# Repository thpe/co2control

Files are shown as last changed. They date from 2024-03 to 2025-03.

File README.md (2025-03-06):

# CO2 control
Monitor for CO2
## Features
 * EIA-485 interface
 * SCD-30 sensor
 * Input volatage 24 V
 * RP-2040
 * 4 LEDs
 * Relay
 * Oxygen Cell input < 150 mV (not yet tested)
 * 0-10 V output
 * 1 wire interface
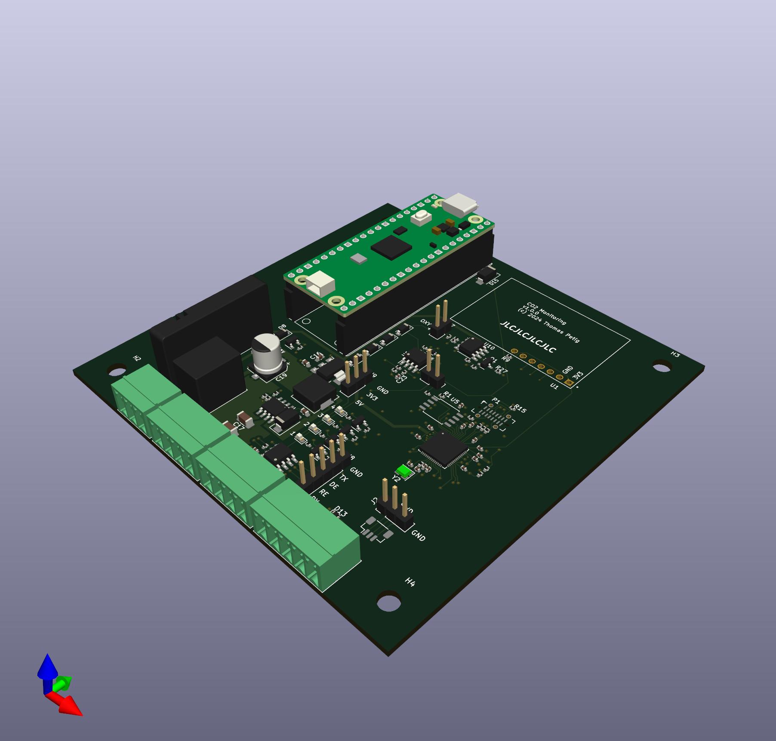
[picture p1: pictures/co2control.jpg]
board3d


## Issues and Limitations
The following issues with the current versions are known:
 * RX/TX to SCD30 need to be switched
 * doesn't connect via USB
   * USB C symbol should have been a receptable, not plug
   * Thus, B7/B6 are not connected to D+/-

## Connection
XLR male, pinout
 * 1. GND, Blue
 * 2. +24V, Blue/White
 * 3. 485A, Orange
 * 4. 485B, Orange/White

## Firmware
The [co2control-fw](https://github.com/thpe/co2control-fw) firmware samples the SCD-30 regulary and exposes the measurements via
modbus.

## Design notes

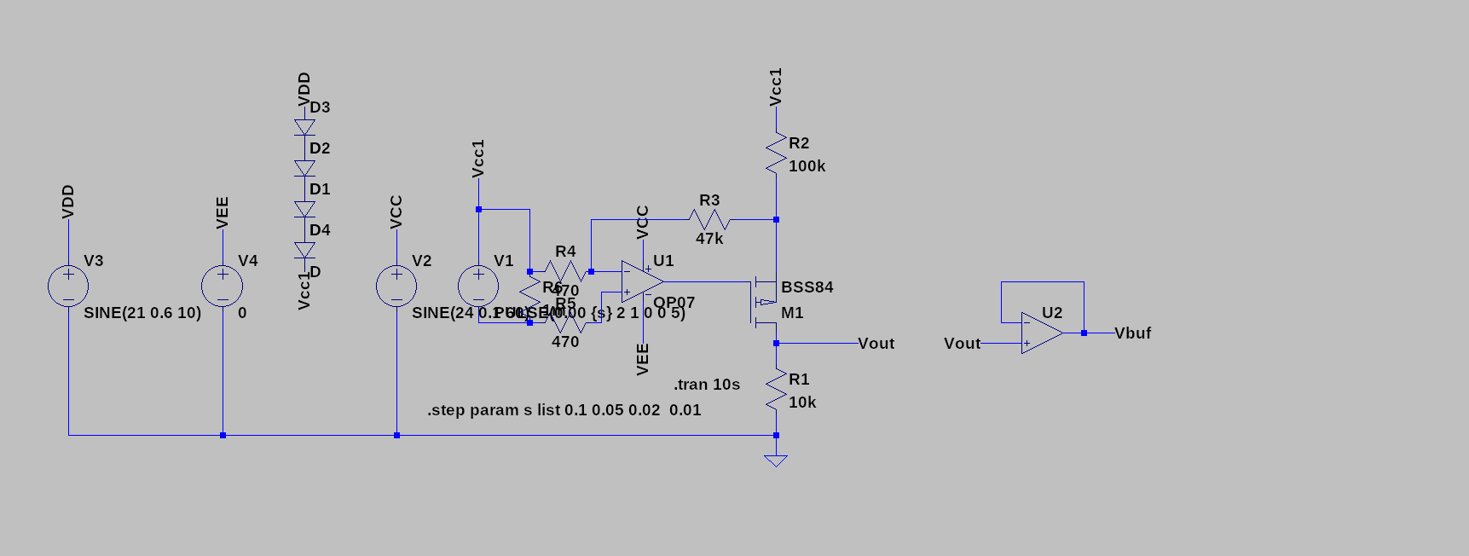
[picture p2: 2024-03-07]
sim/schema.png

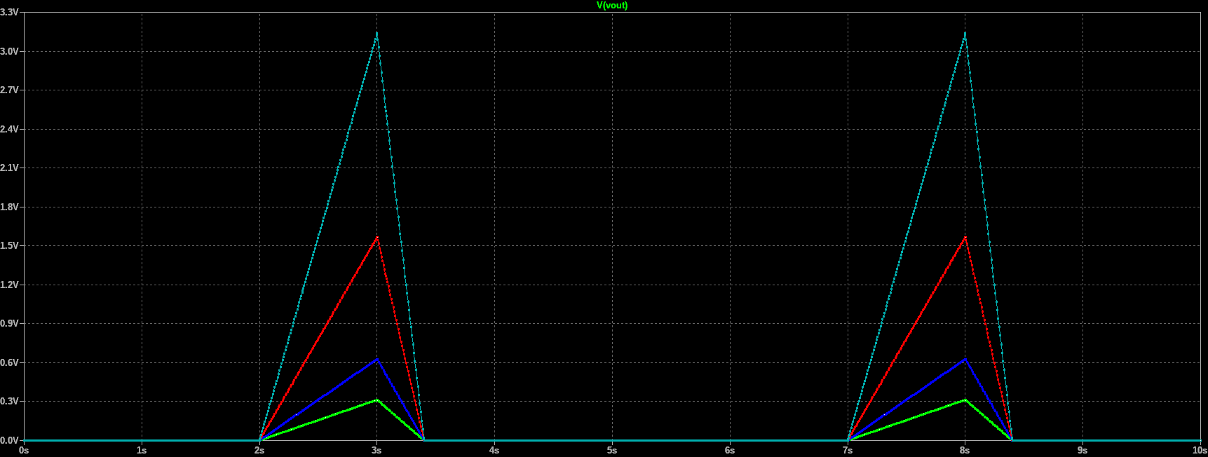
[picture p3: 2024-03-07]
sim/plot.png

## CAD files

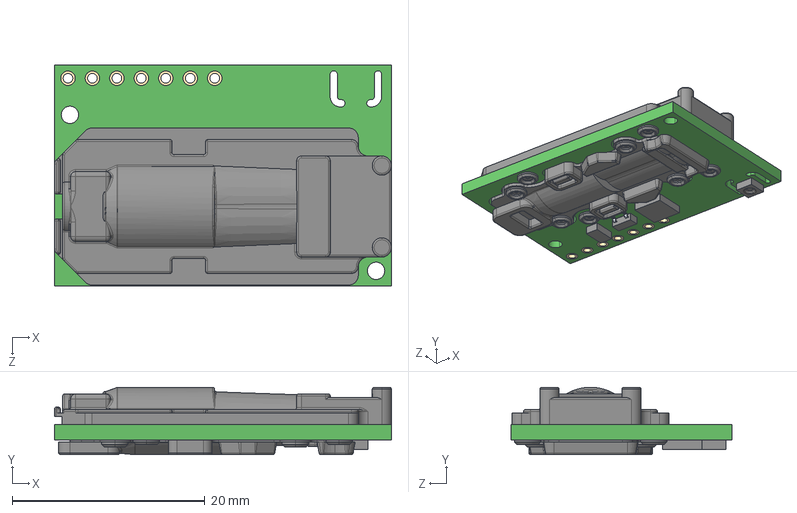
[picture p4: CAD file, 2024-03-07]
scd30/SCD30.step
35.0 x 7.00 x 23.0 mm

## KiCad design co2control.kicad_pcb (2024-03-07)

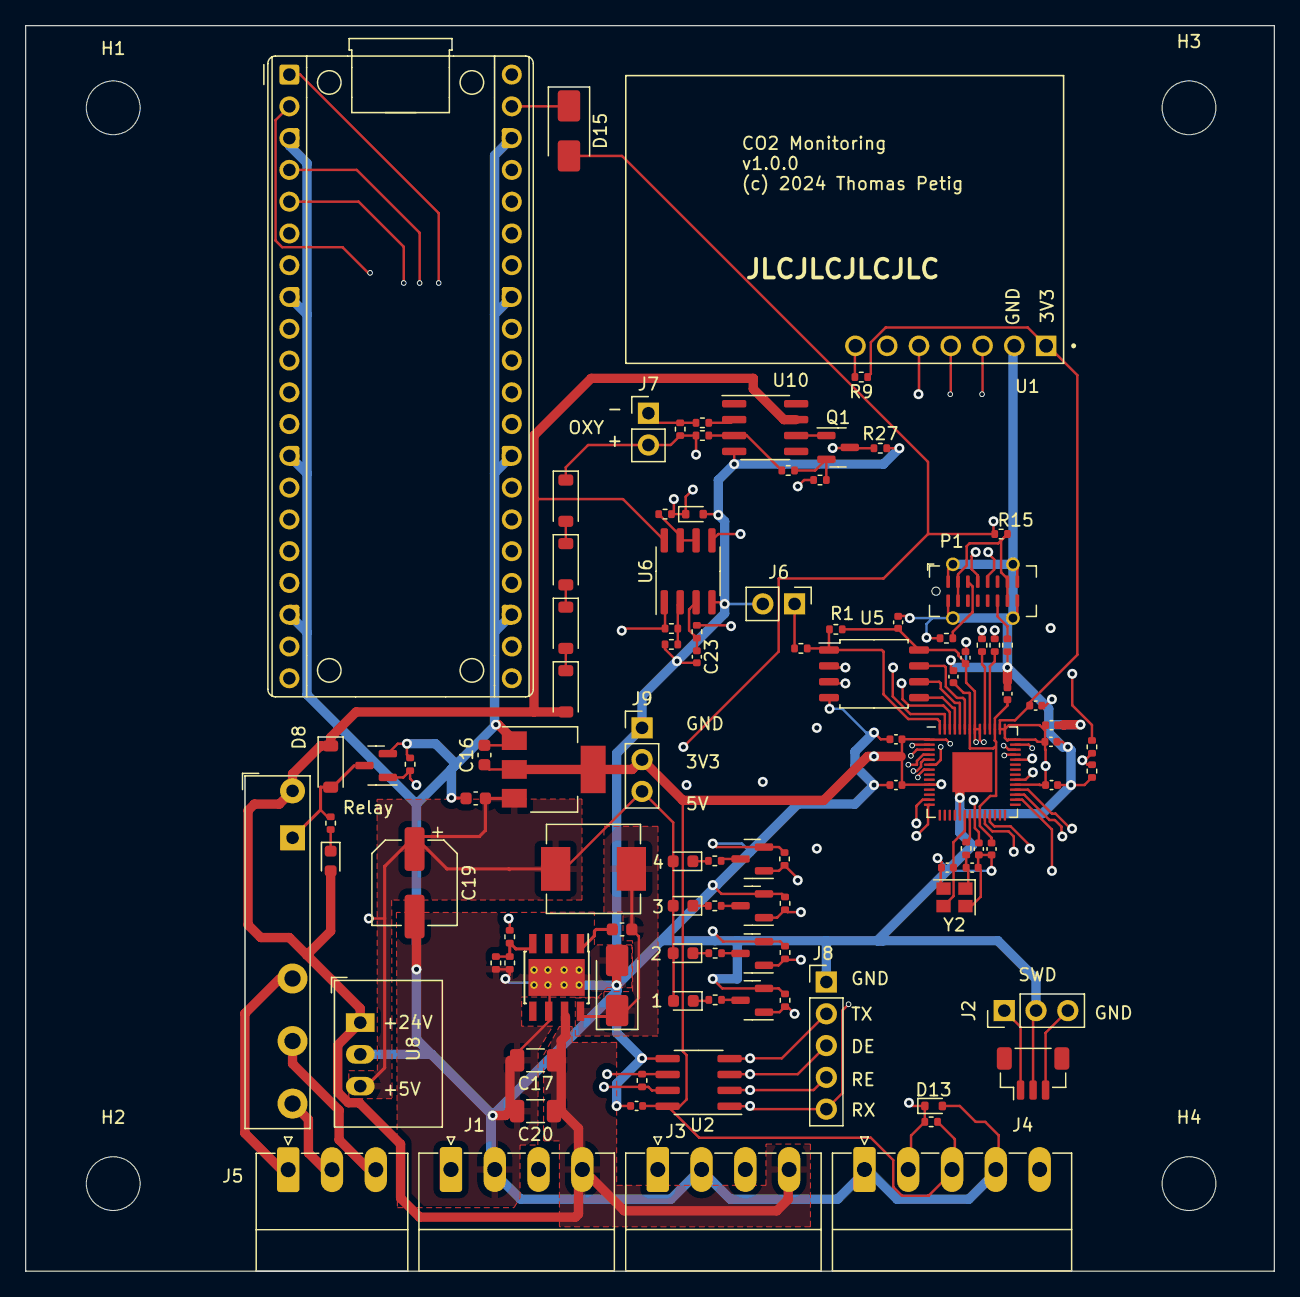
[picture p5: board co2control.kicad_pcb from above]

Board: 4 copper layers, 99.8 x 99.6 mm, 106 parts (0 on the bottom side), 74 nets.

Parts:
C1, C4, C5, C6, C7, C8, C9, C10, C11, C12: 100n; C_0402_1005Metric
C2, C3, C23: 10p; C_0402_1005Metric
C13, C14: 1u; C_0402_1005Metric
C15, C16: 10u; C_0603_1608Metric
C17, C20: 4u7, 50V; C_1206_3216Metric
C18: 10n; C_0603_1608Metric
C19: 220u; CP_Elec_6.3x7.7
C21: 10n; C_0402_1005Metric
D2, D15: B340; D_SMA
D3, D4, D5, D6, D14: LED; LED_0603_1608Metric
D7, D8, D9, D10, D11: 1N4148W; D_SOD-123
D12, D13: MM5Z3V9; D_SOD-523
H1: MountingHole; MountingHole_4.3mm_M4_DIN965
H2, H3, H4: MountingHole; MountingHole_4.3mm_M4
J1, J3: Conn_01x04; PhoenixContact_MC_1,5_4-G-3.5_1x04_P3.50mm_Horizontal
J2: Conn_01x03_Pin; PinHeader_1x03_P2.54mm_Vertical
J4: Conn_01x05; PhoenixContact_MC_1,5_5-G-3.5_1x05_P3.50mm_Horizontal
J5: Conn_01x03; PhoenixContact_MC_1,5_3-G-3.5_1x03_P3.50mm_Horizontal
J6, J7: Conn_01x02; PinHeader_1x02_P2.54mm_Vertical
J8: Conn_01x05; PinHeader_1x05_P2.54mm_Vertical
J9: Conn_01x03; PinHeader_1x03_P2.54mm_Vertical
J10: Conn_01x03_Pin; JST_SH_BM03B-SRSS-TB_1x03-1MP_P1.00mm_Vertical
K1: Relay_SPDT; Relay_SPDT_Finder_34.51_Vertical
L1: 22u; L_Sunlord_MWSA0603S
P1: USB_C_Plug_USB2.0; USB_C_Receptacle_G-Switch_GT-USB-7051x
Q1: Q_PMOS_GSD; SOT-23
Q2, Q3, Q4, Q5, Q6: BSS138; SOT-23
R1, R15: DNF; R_0402_1005Metric
R2, R3, R16: 1k; R_0402_1005Metric
R4, R5: 27; R_0402_1005Metric
R6: 120; R_0402_1005Metric
R7, R9, R17, R19, R20, R27, R32, R33: 10k; R_0402_1005Metric
R8: 3k3; R_0402_1005Metric
R10, R12, R13, R30: 220; R_0402_1005Metric
R11, R22, R25, R26, R28, R29, R31, R36: 100k; R_0402_1005Metric
R14: 1M; R_0402_1005Metric
R18: 1k5; R_0402_1005Metric
R21: 4k7; R_0402_1005Metric
R23, R24: 330; R_0402_1005Metric
R34, R35: 5k1; R_0402_1005Metric
U1: SCD30; MODULE_SCD30
U2: SP3485EN; SOIC-8_3.9x4.9mm_P1.27mm
U3: AP1117-33; SOT-223-3_TabPin2
U4: RP2040; QFN-56-1EP_7x7mm_P0.4mm_EP3.2x3.2mm
U5: W25Q128JVS; SOIC-8_5.23x5.23mm_P1.27mm
U6: LM358; SOIC-8_3.9x4.9mm_P1.27mm
U7: RaspberryPi_Pico; RaspberryPi_Pico_Common_THT
U8: R-78C5.0-1.0; Converter_DCDC_RECOM_R-78E-0.5_THT
U9: TPS5430DDA; TI_SO-PowerPAD-8_ThermalVias
U10: OP07; SOIC-8_3.9x4.9mm_P1.27mm
Y2: 7E12000E10UCG; Crystal_SMD_2520-4Pin_2.5x2.0mm

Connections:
+1V1: C11.1, C12.1, C14.1, U4.23 (DVDD), U4.45 (VREG_VOUT), U4.50 (DVDD)
+3.3V: C1.1, C4.1, C5.1, C6.1, C7.1, C8.1, C9.1, C10.1, C13.1, C16.1, C21.1, J4.3, J9.2, R1.1, R9.1, R17.2, U1.1 (VDD), U2.8 (VCC), U3.2 (VO), U4.1 (IOVDD), U4.10 (IOVDD), U4.22 (IOVDD), U4.33 (IOVDD), U4.42 (IOVDD), U4.43 (ADC_AVDD), U4.44 (VREG_IN), U4.48 (USB_VDD), U4.49 (IOVDD), U5.8 (VCC)
+5V: C15.1, C19.1, D3.2 (A), D4.2 (A), D5.2 (A), D6.2 (A), D15.2 (A), J9.3, L1.2, R7.1, R15.2, R32.1, U3.3 (VI), U8.3 (OUT)
+24V: C17.1, C20.1, D7.2 (A), D8.1 (K), D14.2 (A), J1.4, J3.4, K1.A2, U6.8 (V+), U8.1 (IN), U9.7 (VIN), U10.7 (V+)
/io/1wire: D13.1 (K), J4.2, R17.1, U4.14 (GPIO11), U7.15 (GPIO11)
/io/485A: J1.1, J3.1, R6.1, U2.6 (A)
/io/485B: J1.3, J3.3, R6.2, U2.7 (B)
/io/MODBUS_DE: J8.3, U2.3 (DE), U4.4 (GPIO2), U7.4 (GPIO2)
/io/MODBUS_RE: J8.4, U2.2 (~RE), U4.5 (GPIO3), U7.5 (GPIO3)
/io/MODBUS_RX: J8.5, U2.1 (RO), U4.3 (GPIO1), U7.2 (GPIO1)
/io/MODBUS_TX: J8.2, U2.4 (DI), U4.2 (GPIO0), U7.1 (GPIO0)
/io/OUT1_10V: J4.5, R19.1, U6.1
/io/PWM1: R21.2, U4.13 (GPIO10), U7.14 (GPIO10)
/io/RELAY: Q2.1 (G), R22.2, U4.39 (GPIO27_ADC1), U7.32 (GPIO27_ADC1)
/io/Voxy: D12.1 (K), R16.1, U4.38 (GPIO26_ADC0), U7.31 (GPIO26_ADC0)
/power/PH: C18.2, D2.1 (K), L1.1, U9.8 (PH)
/processing/ADC2: U1.5 (RDY), U4.40 (GPIO28_ADC2), U7.34 (GPIO28_ADC2)
/processing/LED1: Q6.1 (G), R31.2, U4.30 (GPIO19), U7.25 (GPIO19)
/processing/LED2: Q4.1 (G), R11.2, U4.31 (GPIO20), U7.26 (GPIO20)
/processing/LED3: Q5.1 (G), R29.2, U4.32 (GPIO21), U7.27 (GPIO21)
/processing/LED4: Q3.1 (G), R28.2, U4.34 (GPIO22), U7.29 (GPIO22)
/processing/UART1 RX: U1.4 (RX/SDA), U4.7 (GPIO5), U7.7 (GPIO5)
/processing/UART1 TX: U1.3 (TX/SCL), U4.6 (GPIO4), U7.6 (GPIO4)
/processing/USB_D+: P1.A6 (D+), R5.1
/processing/USB_D-: P1.A7 (D-), R4.2
GND: C1.2, C2.1, C3.1, C4.2, C5.2, C6.2, C7.2, C8.2, C9.2, C10.2, C11.2, C12.2, C13.2, C14.2, C15.2, C16.2, C17.2, C19.2, C20.2, C21.2, C23.2, D2.2 (A), D12.2 (A), D13.2 (A), J1.2, J2.2, J3.2, J4.1, J4.4, J6.2, J8.1, J9.1, J10.2, P1.A1 (GND), P1.A12 (GND), P1.B1 (GND), P1.B12 (GND), P1.S1 (SHIELD), Q2.2 (S), Q3.2 (S), Q4.2 (S), Q5.2 (S), Q6.2 (S), R8.2, R11.1, R20.1, R22.1, R27.2, R28.1, R29.1, R31.1, R33.2, R34.1, R35.1, R36.2, U1.2 (GND), U2.5 (GND), U3.1 (GND), U4.19 (TESTEN), U4.57 (GND), U5.4 (GND), U6.4 (V-), U7.3 (GND), U7.8 (GND), U7.13 (GND), U7.18 (GND), U7.23 (GND), U7.28 (GND), U7.33 (AGND), U7.38 (GND), U8.2 (GND), U9.6 (GND), U9.9 (GNDPAD), U10.4 (V-), Y2.2, Y2.4
unnamed: C3.2, R3.1, Y2.1
unnamed: D3.1 (K), R10.1
unnamed: D4.1 (K), R12.1
unnamed: D5.1 (K), R30.1
unnamed: D6.1 (K), R13.1
unnamed: D7.1 (K), D9.2 (A)
unnamed: D8.2 (A), K1.A1, Q2.3 (D), R18.2
unnamed: D9.1 (K), D10.2 (A)
unnamed: D10.1 (K), D11.2 (A)
unnamed: D11.1 (K), J7.2, R14.1, R23.1, R26.1
unnamed: D14.1 (K), R18.1
unnamed: D15.1 (K), U7.39 (VSYS)
unnamed: J5.1, K1.12
unnamed: J5.2, K1.14
unnamed: J5.3, K1.11
unnamed: J6.1, R2.1
unnamed: J7.1, R14.2, R24.1
unnamed: J2.1, J10.1, U4.24 (SWCLK)
unnamed: J2.3, J10.3, U4.25 (SWD)
unnamed: P1.A5 (CC), R34.2
unnamed: P1.A4 (VBUS), P1.A9 (VBUS), P1.B4 (VBUS), P1.B9 (VBUS), R15.1
unnamed: P1.B5 (VCONN), R35.2
unnamed: Q1.3 (D), R27.1, U6.5 (+)
unnamed: Q1.1 (G), U10.6
unnamed: Q1.2 (S), R25.2, R26.2
unnamed: Q3.3 (D), R13.2
unnamed: Q4.3 (D), R10.2
unnamed: Q5.3 (D), R12.2
unnamed: Q6.3 (D), R30.2
unnamed: R9.2, U1.7 (SEL)
unnamed: R32.2, R33.1, U4.41 (GPIO29_ADC3)
unnamed: U4.52 (QSPI_SCLK), U5.6 (CLK)
unnamed: U4.53 (QSPI_SD0), U5.5 (DI(IO0))
unnamed: U4.55 (QSPI_SD1), U5.2 (DO(IO1))
unnamed: U4.54 (QSPI_SD2), U5.3 (IO2)
unnamed: U4.51 (QSPI_SD3), U5.7 (IO3)
unnamed: R1.2, R2.2, U4.56 (QSPI_SS), U5.1 (~CS)
unnamed: R4.1, U4.46 (USB_DM)
unnamed: R5.2, U4.47 (USB_DP)
unnamed: C2.2, U4.20 (XIN), Y2.3
unnamed: R3.2, U4.21 (XOUT)
unnamed: C23.1, R21.1, U6.3 (+)
unnamed: R19.2, R20.2, U6.2 (-)
unnamed: R16.2, U6.6 (-), U6.7
unnamed: C18.1, U9.1 (BOOT)
unnamed: R7.2, R8.1, R36.1, U9.4 (VSENSE)
unnamed: R23.2, R25.1, U10.3 (+)
unnamed: R24.2, U10.2 (-)

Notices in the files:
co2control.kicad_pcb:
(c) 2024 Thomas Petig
